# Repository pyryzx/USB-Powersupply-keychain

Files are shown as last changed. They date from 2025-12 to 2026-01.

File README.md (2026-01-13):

# Multi-Rail Power Supply Keychain (USB-C PD)

A compact, keychain-sized **USB-C powered** power supply that has four power rails:

- **+1.8 V** (up to 1.5 A)
- **+3.3 V** (up to 1.5 A)
- **+5 V** (up to 1.5 A)
- **+12 V (VBUS passthrough)** from the USB-C PD source

Clip this onto your keys, plug it into a USB-C PD charger, and you’ve got the most common lab voltages available from a single tiny board.

---

## Features

- USB-C input with **USB Power Delivery negotiation** (requests 12 V from a capable source)
- Multi-rail DC/DC conversion to generate **1.8 V, 3.3 V, and 5 V**
- **12 V VBUS rail is also available** as an output (source-dependent)
- Compact PCB with **keychain hole**

---

## Electrical Specs (Target)

> Real limits depend heavily on the USB-C PD source, total load, copper/thermal conditions, and airflow.

### Outputs

| Rail | Nominal Voltage | Max Current (design target) | Notes |
|---|---:|---:|---|
| +1.8V | 1.8 V | 1.5 A | Buck regulated |
| +3.3V | 3.3 V | 1.5 A | Buck regulated |
| +5V | 5.0 V | 1.5 A | Buck regulated |
| +12V | 12 V | Source-dependent | Direct from negotiated VBUS |

### Power Budget 

beware that even if each rail is “rated” for 1.5 A it is source dependent. 

Example (typical PD): **12 V × 3 A = 36 W available**  
Loads:
- 5 V @ 1.5 A ≈ 7.5 W  
- 3.3 V @ 1.5 A ≈ 5.0 W  
- 1.8 V @ 1.5 A ≈ 2.7 W  
Total ≈ 15.2 W (plus conversion losses)

Beware that current design is not yet optimized to be run at full capacity all the time. Heat generated is still a problem when run at max load.

## Output Connector / Pinout

### J3

Pin order (as labeled on schematic / silkscreen intent):

1. **+1.8V**
2. **+3.3V**
3. **+5V**
4. **+12V**
5. **GND**

---

## How It Works 

1. **USB-C input** comes in on the Type-C receptacle.
2. A **USB-C PD sink controller (CYPD3177-24LQ)** negotiates with the charger to request **12 V** output.
3. Once VBUS is valid, a small input switching/protection stage connects the negotiated rail to the board.
4. A **multi-output buck regulator (TPS65581PWP)** generates:
   - **1.8 V** (via L1)
   - **3.3 V** (via L2)
   - **5 V** (via L3)
5. The negotiated **+12 V VBUS** rail is also routed to the output header.

See: `schematic_keychain V2.pdf`. :contentReference[oaicite:1]{index=1}

---

## What This Is For

- Powering sensors, dev boards, and small embedded prototypes
- Quick “bench supply” substitute for field work
- Testing boards that need 1.8 V / 3.3 V / 5 V without dragging a lab PSU around

---

## What This Is NOT For

- Not a charger / power bank
- Not safety-certified equipment
- Not intended for life-critical, medical, automotive, or mains-related applications
- Not meant for inductive loads / motors directly 

---

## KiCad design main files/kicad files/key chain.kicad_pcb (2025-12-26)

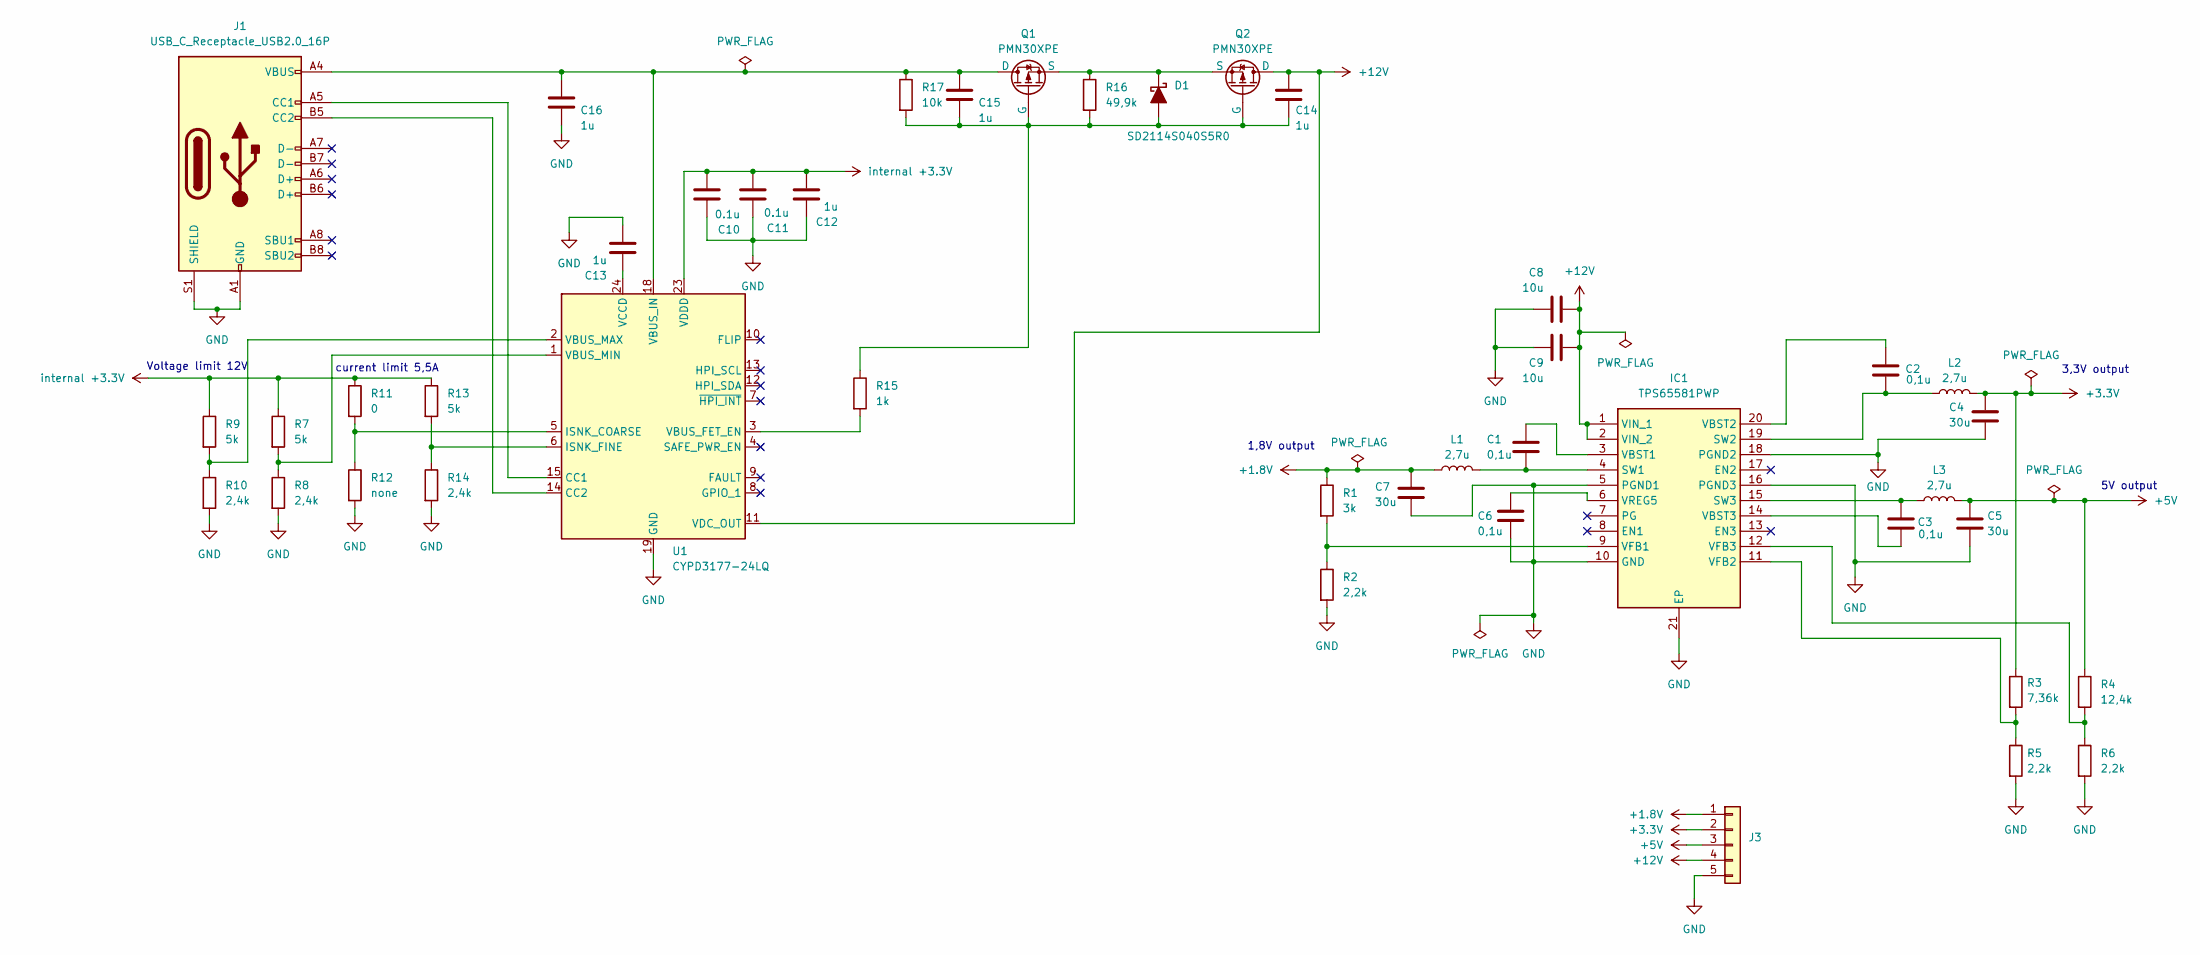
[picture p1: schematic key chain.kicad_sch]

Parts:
C1, C2, C3, C6: 0,1u; C_0603_1608Metric_Pad1.08x0.95mm_HandSolder
C4, C5, C7: 30u; C_0603_1608Metric_Pad1.08x0.95mm_HandSolder
C8, C9: 10u; C_0603_1608Metric_Pad1.08x0.95mm_HandSolder
C10, C11: 0.1u; C_0603_1608Metric_Pad1.08x0.95mm_HandSolder
C12, C13, C14, C15, C16: 1u; C_0603_1608Metric_Pad1.08x0.95mm_HandSolder
D1: SD2114S040S5R0
IC1: TPS65581PWP; SOP65P640X120-21N; Mouser Part Number 595-TPS65581PWP
J1: USB_C_Receptacle_USB2.0_16P; USB_C_Receptacle_HRO_TYPE-C-31-M-12
J3: Conn_01x05; PinSocket_1x05_P2.54mm_Vertical
L1, L2, L3: 2,7u; L_1812_4532Metric_Pad1.30x3.40mm_HandSolder
Q1, Q2: PMN30XPE; TSOP-6_1.65x3.05mm_P0.95mm
R1: 3k; R_0603_1608Metric_Pad0.98x0.95mm_HandSolder
R2, R5, R6: 2,2k; R_0603_1608Metric_Pad0.98x0.95mm_HandSolder
R3: 7,36k; R_0603_1608Metric_Pad0.98x0.95mm_HandSolder
R4: 12,4k; R_0603_1608Metric_Pad0.98x0.95mm_HandSolder
R7, R9, R13: 5k; R_0603_1608Metric_Pad0.98x0.95mm_HandSolder
R8, R10, R14: 2,4k; R_0603_1608Metric_Pad0.98x0.95mm_HandSolder
R11: 0; R_0603_1608Metric_Pad0.98x0.95mm_HandSolder
R12: none; R_0603_1608Metric_Pad0.98x0.95mm_HandSolder
R15: 1k; R_0603_1608Metric_Pad0.98x0.95mm_HandSolder
R16: 49,9k; R_0603_1608Metric_Pad0.98x0.95mm_HandSolder
R17: 10k; R_0603_1608Metric_Pad0.98x0.95mm_HandSolder
U1: CYPD3177-24LQ; QFN-24-1EP_4x4mm_P0.5mm_EP2.75x2.75mm

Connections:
+1.8V: C7.1, J3.1, L1.1, R1.1
+3.3V: C4.1, J3.2, L2.2, R3.1
+5V: C5.1, J3.3, L3.2, R4.1
+12V: C8.2, C9.2, C14.1, IC1.1 (VIN_1), IC1.2 (VIN_2), J3.4, Q2.1 (D), U1.11 (VDC_OUT)
GND: C4.2, C5.2, C6.2, C7.2, C8.1, C9.1, C10.1, C11.1, C12.1, C13.2, C16.2, IC1.5 (PGND1), IC1.10 (GND), IC1.16 (PGND3), IC1.18 (PGND2), IC1.21 (EP), J1.A1 (GND), J1.A12 (GND), J1.B1 (GND), J1.B12 (GND), J1.S1 (SHIELD), J3.5, R2.2, R5.2, R6.2, R8.2, R10.2, R12.2, R14.2, U1.19 (GND), U1.22 (GND), U1.25 (GND)
unnamed: C14.2, C15.2, D1.2 (A), Q1.2 (G), Q2.2 (G), R15.1, R16.2, R17.2
unnamed: D1.1 (K), Q1.3 (S), Q2.3 (S), R16.1
unnamed: C1.2, IC1.4 (SW1), L1.2
unnamed: C2.1, IC1.19 (SW2), L2.1
unnamed: C3.2, IC1.15 (SW3), L3.1
unnamed: C1.1, IC1.3 (VBST1)
unnamed: C2.2, IC1.20 (VBST2)
unnamed: C3.1, IC1.14 (VBST3)
unnamed: IC1.9 (VFB1), R1.2, R2.1
unnamed: IC1.11 (VFB2), R3.2, R5.1
unnamed: IC1.12 (VFB3), R4.2, R6.1
unnamed: C6.1, IC1.6 (VREG5)
unnamed: J1.A5 (CC1), U1.15 (CC1)
unnamed: J1.B5 (CC2), U1.14 (CC2)
unnamed: C15.1, C16.1, J1.A4 (VBUS), J1.A9 (VBUS), J1.B4 (VBUS), J1.B9 (VBUS), Q1.1 (D), R17.1, U1.18 (VBUS_IN)
unnamed: R11.2, R12.1, U1.5 (ISNK_COARSE)
unnamed: R13.2, R14.1, U1.6 (ISNK_FINE)
unnamed: R15.2, U1.3 (VBUS_FET_EN)
unnamed: R9.2, R10.1, U1.2 (VBUS_MAX)
unnamed: R7.2, R8.1, U1.1 (VBUS_MIN)
unnamed: C13.1, U1.24 (VCCD)
internal +3.3V: C10.2, C11.2, C12.2, R7.1, R9.1, R11.1, R13.1, U1.23 (VDDD)

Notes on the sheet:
1,8V output
current limit 5,5A
3,3V output
5V output
Voltage limit 12V

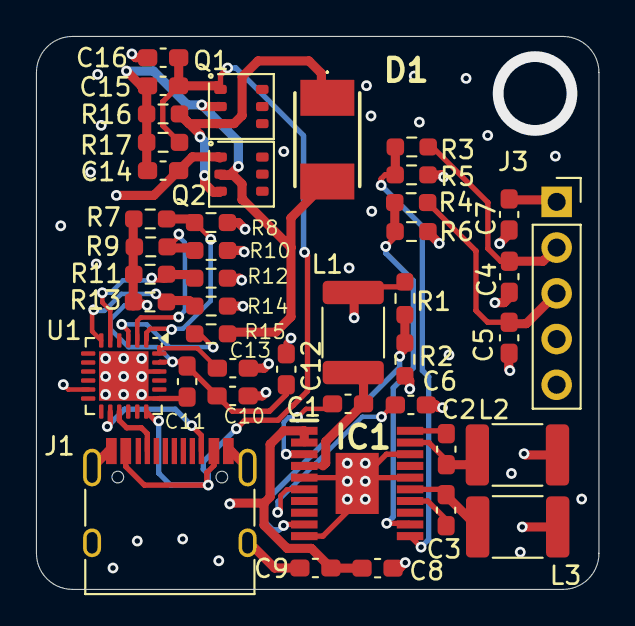
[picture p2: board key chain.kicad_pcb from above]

Board: 4 copper layers, 31.2 x 30.7 mm, 43 parts (0 on the bottom side), 27 nets.
